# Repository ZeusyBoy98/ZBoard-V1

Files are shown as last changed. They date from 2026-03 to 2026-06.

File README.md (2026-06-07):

# ZBoard-V1
Video: https://github.com/ZeusyBoy98/ZBoard-V1/blob/main/IMG/ZBoard-V1-Video.mp4.  
The ultimate minimalistic 75% low-profile keyboard that fits my needs!
Made for Hack Club Fallout.

## Zine
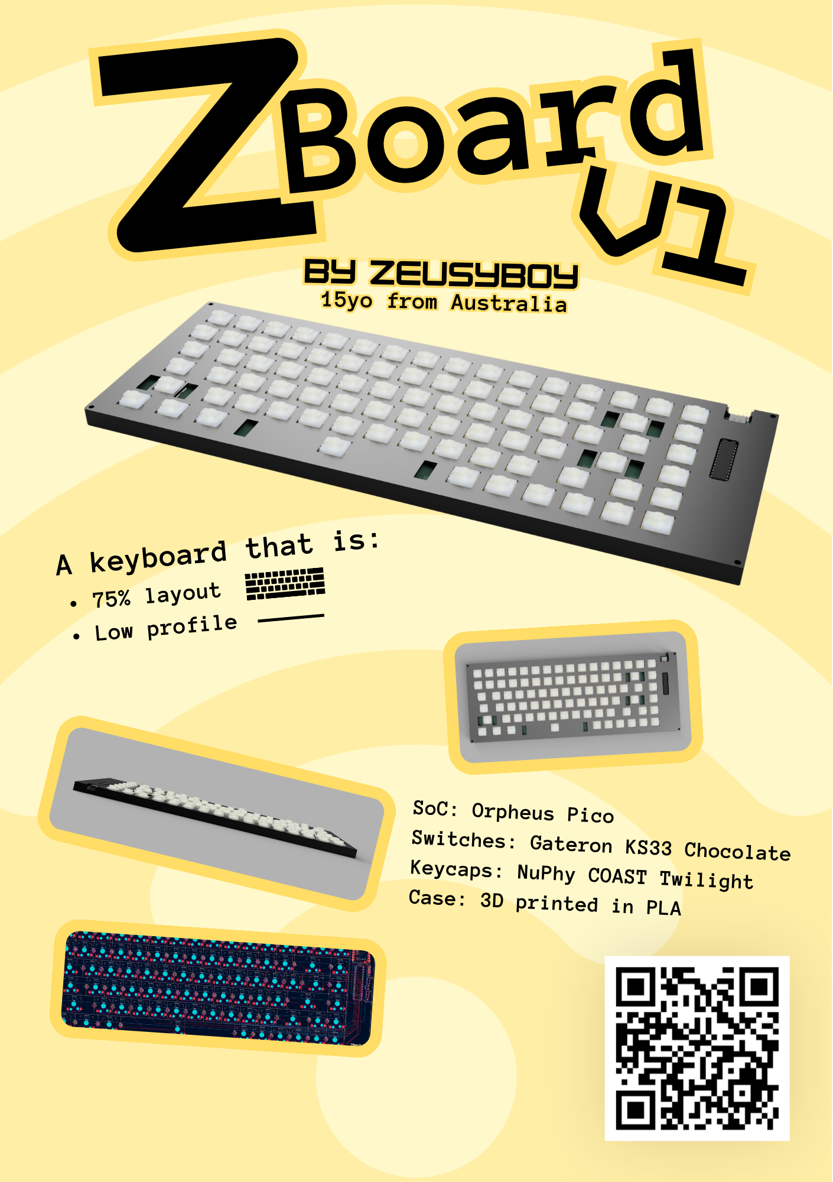
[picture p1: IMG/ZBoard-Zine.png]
zine


## What does it do?
It's a 75% low-profile keyboard with Gateron KS33 Chocolate Switches, NuPhy COAST Twilight Keycaps, and a 3D printed shell and plate.

## Why?
Because I hate my current keyboard options. I have a Corsair K70 Core which sucks for anything other than gaming, and some old HP keyboard which doesn't register switch presses half the time. So I decided to build my own keyboard. My requirements were for it to be low profile & 75%, so it can fit anywere for any situation, and use switches which I really enjoy pressing. In the end, this is the design I came up with and I could not be happier.

## Motivation
I don't have a good keyboard. My options are a gaming keyboard that double presses, or a membrane keyboard that doesn't press. This should fix both those issues and be actually enjoyable to use.

## How?
In order to make this project for yourself, you'll need to purchase/3D print the items in the bill of materials below.

| Qty | Component | Link | Price Individual (USD) | Price Sum (USD) |
| --- | --- | --- | --- | --- |
| 100 | Diode | [LCSC](https://www.lcsc.com/product-detail/C917030.html?s_z=n_1N4148W) | 0.0058 | 0.58 |
| 1 | Switches (110 KS33 Chocolate) | [Gateron](https://www.gateron.com/products/gateron-ks-33-low-profile-20-chocolate-switch?VariantsId=11140) | 39.60 | 39.60 |
| 1 | Hotswap Sockets | [Gateron](https://www.gateron.com/products/gateron-low-profile-switch-hot-swap-pcb-socket?VariantsId=10234)  | 11.00 | 11.00 |
| 1 | Stabilizers | [Gateron](https://www.gateron.com/products/gateron-low-profile-plate-mounted-stabilizer?VariantsId=10540) | 8.00 | 8.00 |
| 1 | Orpheus Pico | Hack Club Flavourtown | Already owned | Already owned |
| 1 | Heat set insert | [Core Electronics](https://core-electronics.com.au/brass-heat-set-inserts-for-plastic-m3-x-3mm-50-pack.html) | Already owned | (8.39) |
| 1 | 5mm M3 Screw | [Core Electronics](https://core-electronics.com.au/machine-screw-m3-5mm-length-phillips-25-pack.html) | Already owned | (2.24) |
| 1 | Case Pieces | CAD/ZBoard-V1-Print.3mf | 3D printing (220g filament) | |
| 1 | Keycap Set | CAD/ZBoard-V1-Print.3mf | 3D printing<br>(70g filament) | (Total 3D printing: 4.61) |
| 1 | PCB | PCB/production/ZBoard_V1.zip | | 21.90 |
| Shipping | | | | 8.60+21.28+10.77=40.65 |
| Total | | | | 99.83 |

### Build Guide:

#### 1. Preparation<br>
Before starting, make sure you have:
<ul>
<li>All components from the BOM
<li>A soldering iron + solder
<li>Tweezers (there are lots of small components)
<li>Flux (helpful)
<li>A screwdriver
<li>A 3D printer (or get the printed parts from someone else) - Print file at CAD/ZBoard-v1-Print.3mf
</ul>

#### 2. Soldering
Take your pcb and begin soldering components to it<br>
Recommended order:
<ul>
<li>SMD Components (Diodes, hot swap sockets)
<li>Microcontroller (Orpheus Pico)
</ul>

#### 3. Switches + Stabilizers
Insert each individual keyboard switch first, then do the stabilizers. Make sure every switch is properly seated in the socket.

#### 4. Case + Keycaps
<ul>
<li>3D print the case pieces and keycaps.
<li>Insert heat-set inserts with soldering iron into holes in bottom part of case.
<li>Place PCB into case and screw case closed with M3 Screws
<li>Put keycaps onto switches
</ul>

#### 5. Flash ZMK firmware
<ul>
<li>Plug the keyboard in via USB
<li>Double press the boot button to enter bootloader
<li>A new USB drive will appear
<li>Copy Firmware/zboard_zboardv1_default.uf2 onto the new USB drive
<li>Wait for Firmware to finish flashing
</ul>

Enjoy your ZBoard!

## Video
video

## Renders
Note: these renders are from the old version so they don't show the pi pico
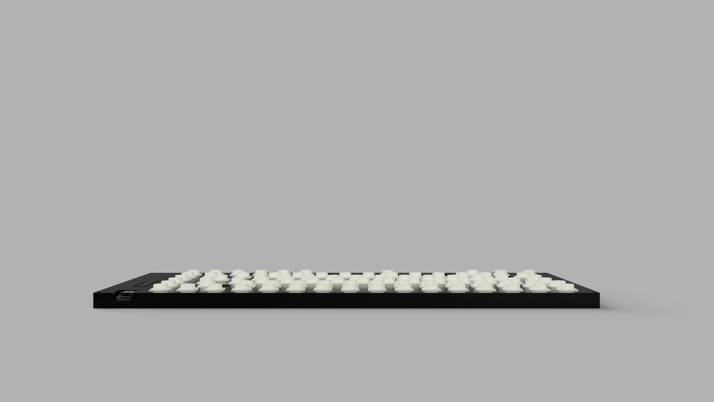
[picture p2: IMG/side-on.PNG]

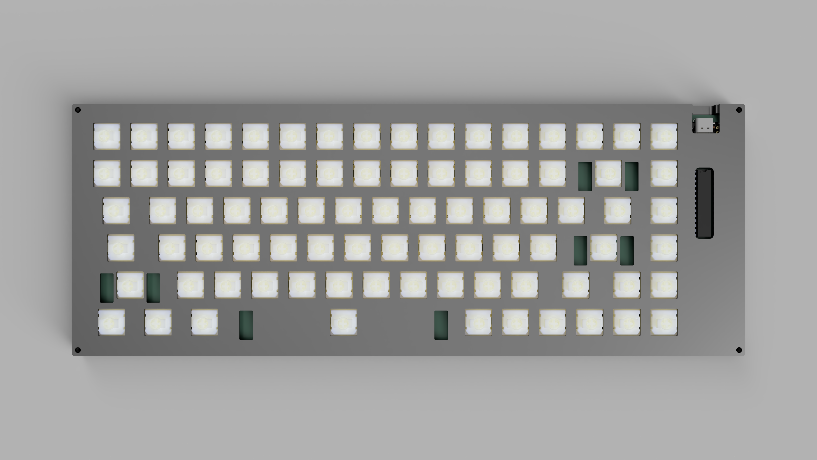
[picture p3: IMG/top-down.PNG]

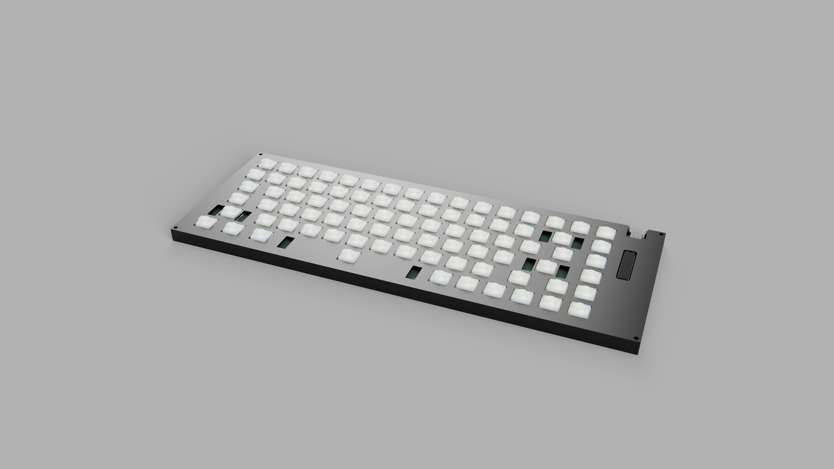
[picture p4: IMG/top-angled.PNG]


## Designing
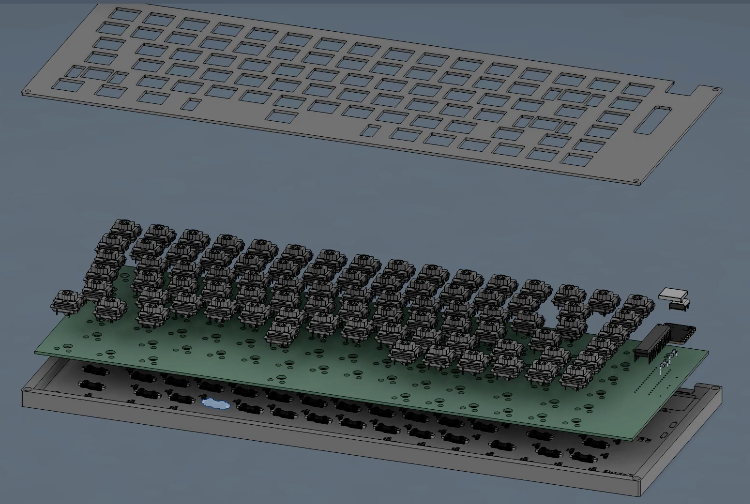
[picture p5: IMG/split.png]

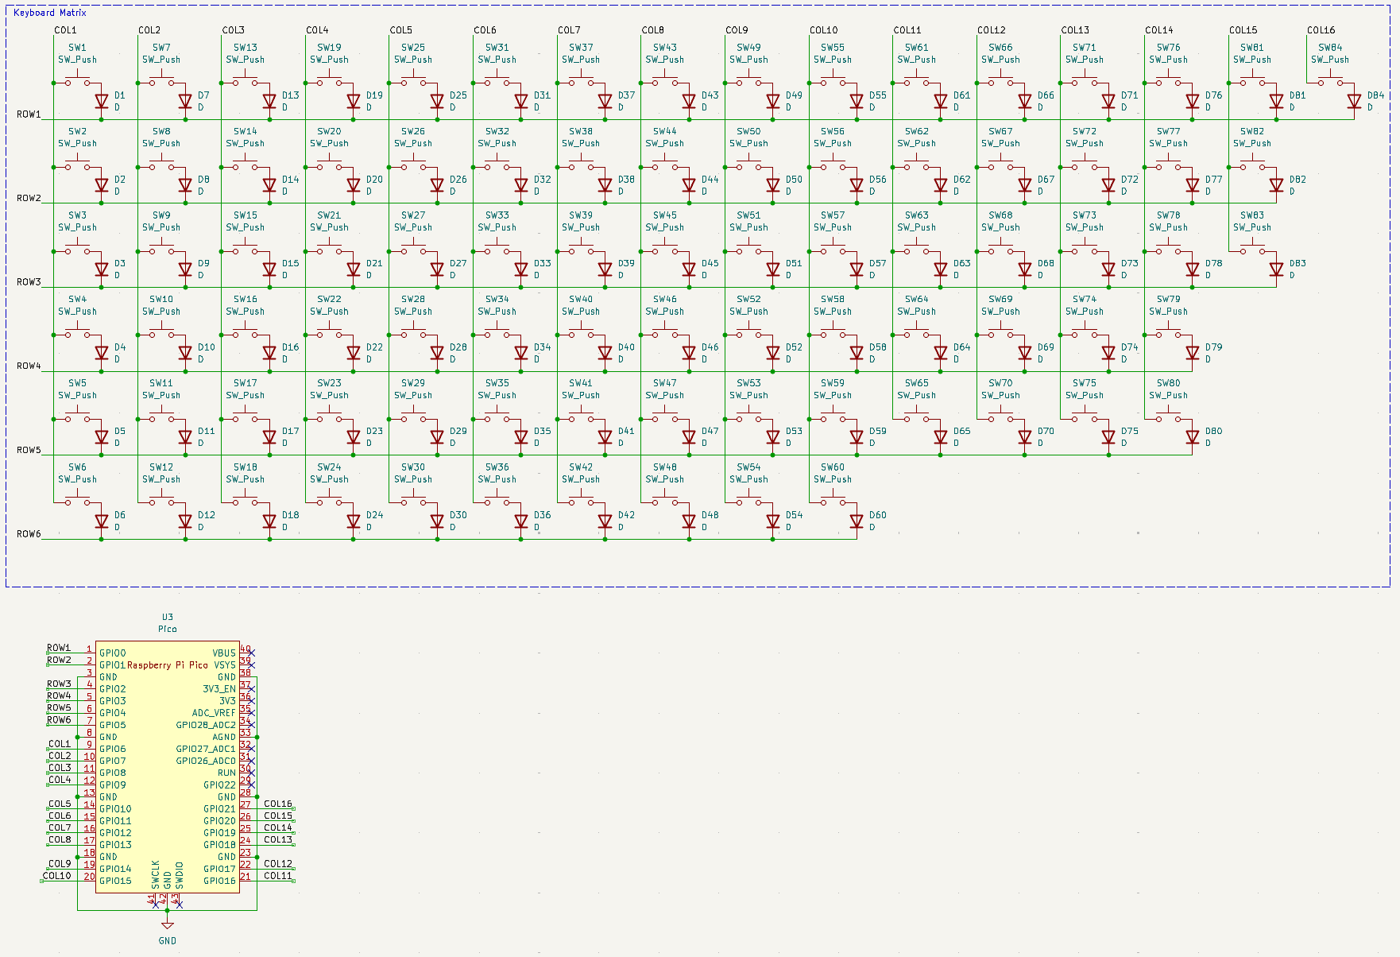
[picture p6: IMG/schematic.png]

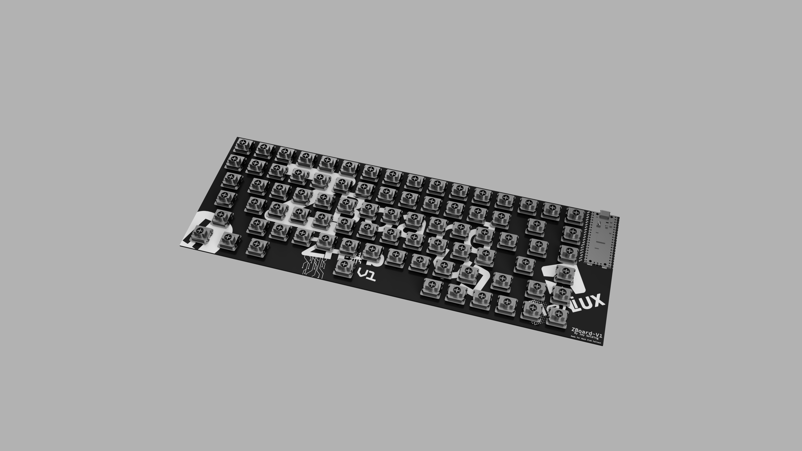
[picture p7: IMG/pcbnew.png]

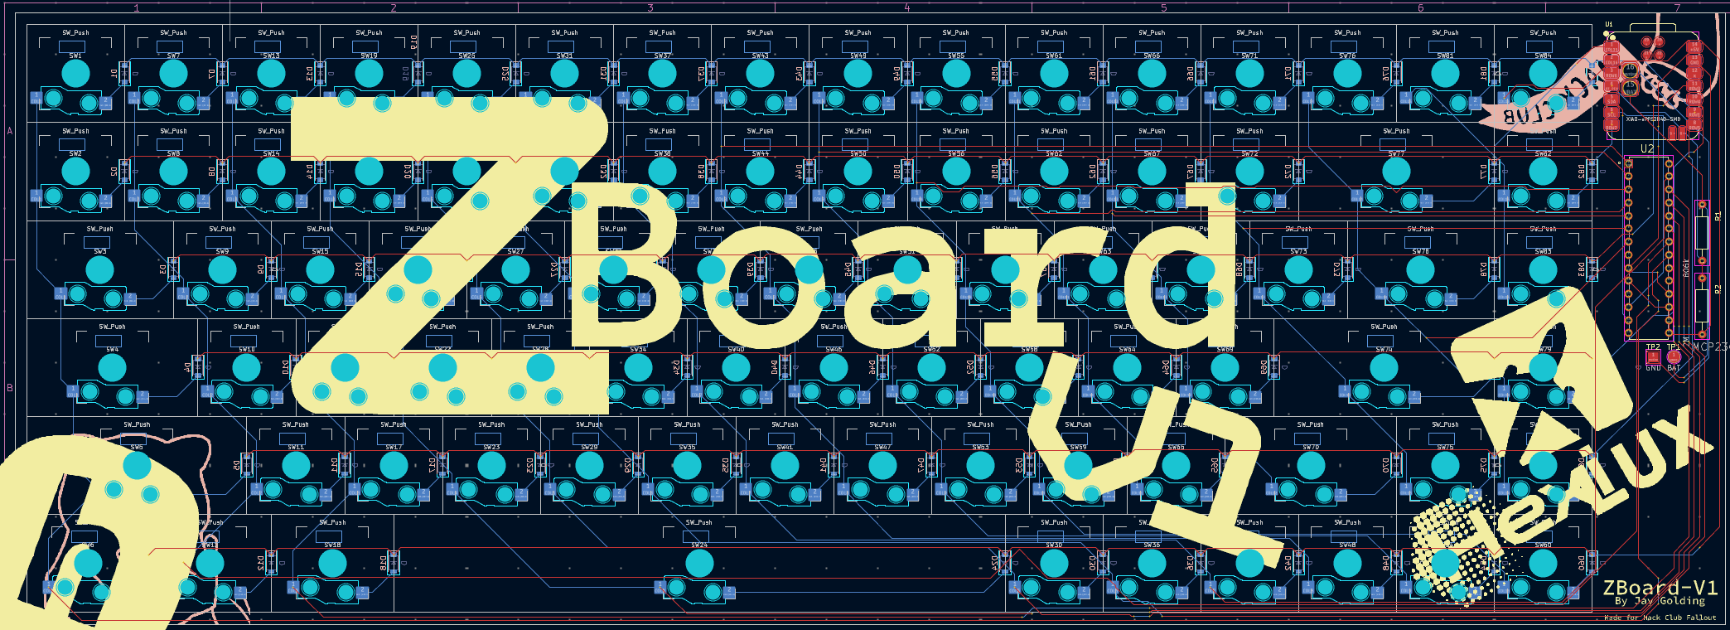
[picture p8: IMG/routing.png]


Here's the version with more personality:
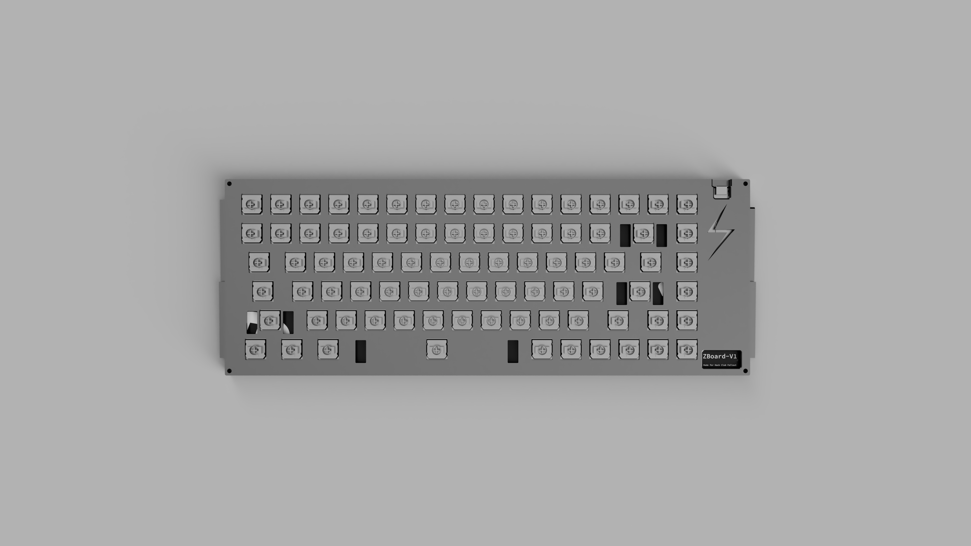
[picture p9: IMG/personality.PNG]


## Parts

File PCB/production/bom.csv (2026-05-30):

Designator | Footprint | Quantity | Value | LCSC Part #
D1, D10, D11, D12, D13, D14, D15, D16, D17, D18, D19, D2, D20, D21, D22, D23, D24, D25, D26, D27, D28, D29, D3, D30, D31, D32, D33, D34, D35, D36, D37, D38, D39, D4, D40, D41, D42, D43, D44, D45, D46, D47, D48, D49, D5, D50, D51, D52, D53, D54, D55, D56, D57, D58, D59, D6, D60, D61, D62, D63, D64, D65, D66, D67, D68, D69, D7, D70, D71, D72, D73, D74, D75, D76, D77, D78, D79, D8, D80, D81, D82, D83, D84, D9 | D_SOD-123 | 84 | D
SW1, SW10, SW11, SW13, SW14, SW15, SW16, SW17, SW19, SW2, SW20, SW21, SW22, SW23, SW25, SW26, SW27, SW28, SW29, SW30, SW31, SW32, SW33, SW34, SW35, SW36, SW37, SW38, SW39, SW40, SW41, SW42, SW43, SW44, SW45, SW46, SW47, SW48, SW49, SW50, SW51, SW52, SW53, SW54, SW55, SW56, SW57, SW58, SW59, SW60, SW61, SW62, SW63, SW64, SW65, SW66, SW67, SW68, SW69, SW7, SW71, SW72, SW73, SW75, SW76, SW79, SW8, SW80, SW81, SW82, SW83, SW84, SW9 | Gateron-KS33-Hotswap-1U | 73 | SW_Push
SW12, SW18, SW6 | Gateron-KS33-Hotswap-1.25U | 3 | SW_Push
SW24 | Gateron-KS33-Hotswap-6.25U | 1 | SW_Push
SW3, SW78 | Gateron-KS33-Hotswap-1.5U | 2 | SW_Push
SW4, SW70 | Gateron-KS33-Hotswap-1.75U | 2 | SW_Push
SW5, SW74 | Gateron-KS33-Hotswap-2.25U | 2 | SW_Push
SW77 | Gateron-KS33-Hotswap-2U | 1 | SW_Push
U3 | RPi_Pico_SMD_TH | 1 | Pico

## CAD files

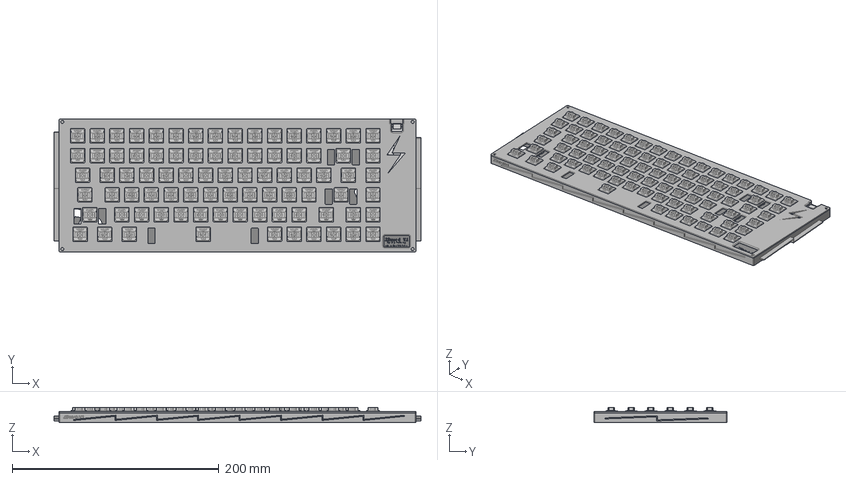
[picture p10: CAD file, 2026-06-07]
CAD/Personality/ZBoard-V1-Full.stp
355.0 x 129.0 x 14.6 mm

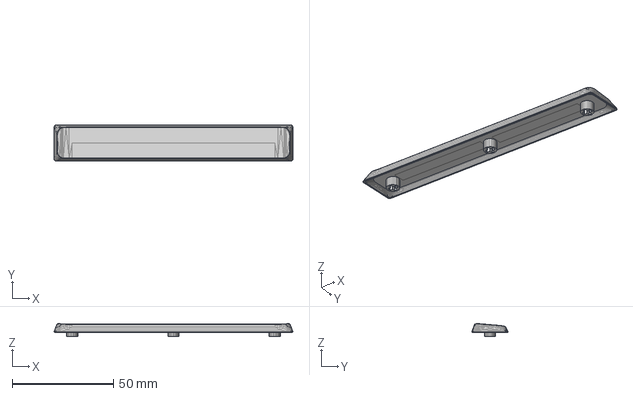
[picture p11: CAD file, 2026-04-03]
CAD/Keycaps/Keycap-6.25u.step
118.0 x 18.0 x 6.23 mm

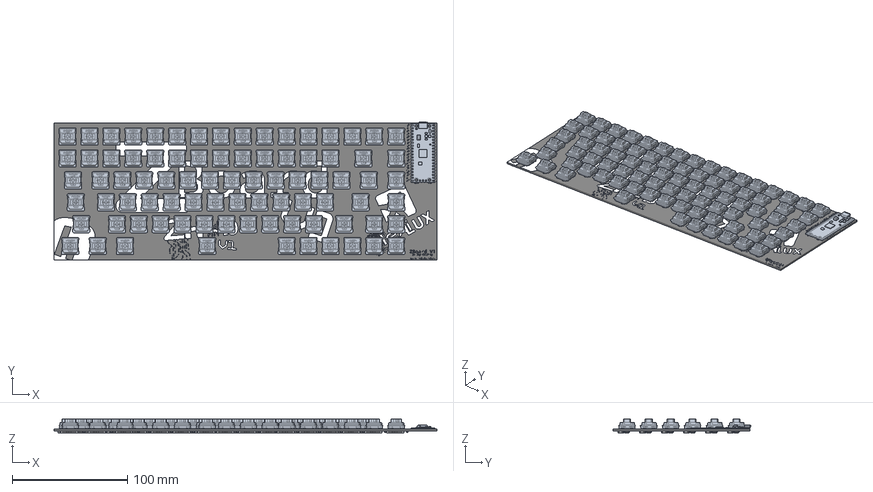
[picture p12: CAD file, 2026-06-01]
CAD/Parts/ZBoard-V1-PCB.step
333.0 x 119.7 x 12.5 mm
ZBoard-V1-PCB 1.1.1
D_SOD-123 x 84
Gateron-KS33-Socket x 84
KS-33 x 84
ZBoard V1_silkscreen x 2
ZBoard V1_PCB

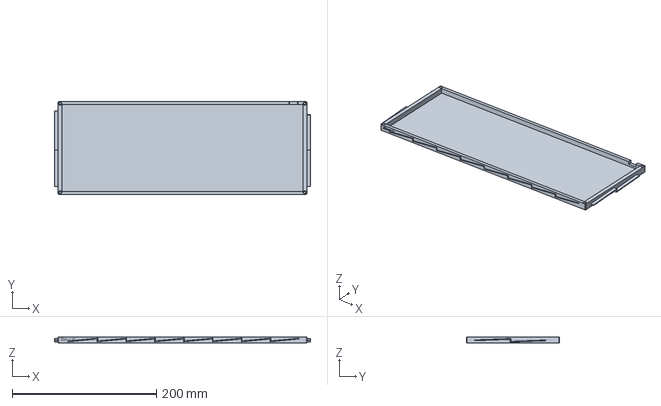
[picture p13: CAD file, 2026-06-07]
CAD/Personality/ZBoard-V1-Bottom.stp
355.0 x 129.0 x 9.00 mm

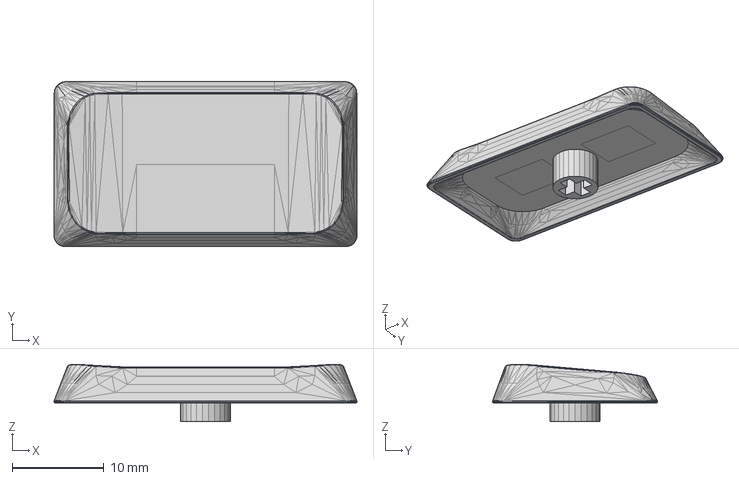
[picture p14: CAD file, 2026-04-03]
CAD/Keycaps/Keycap-1.5u.step
33.0 x 18.0 x 6.23 mm

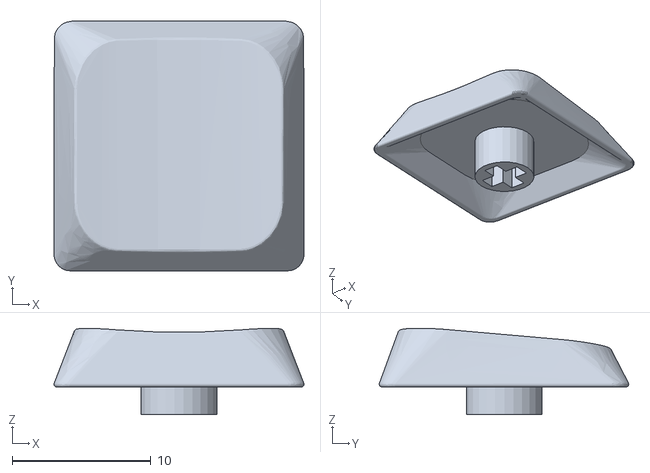
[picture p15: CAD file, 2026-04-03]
CAD/Parts/keycap.stl
18.0 x 18.0 x 6.23

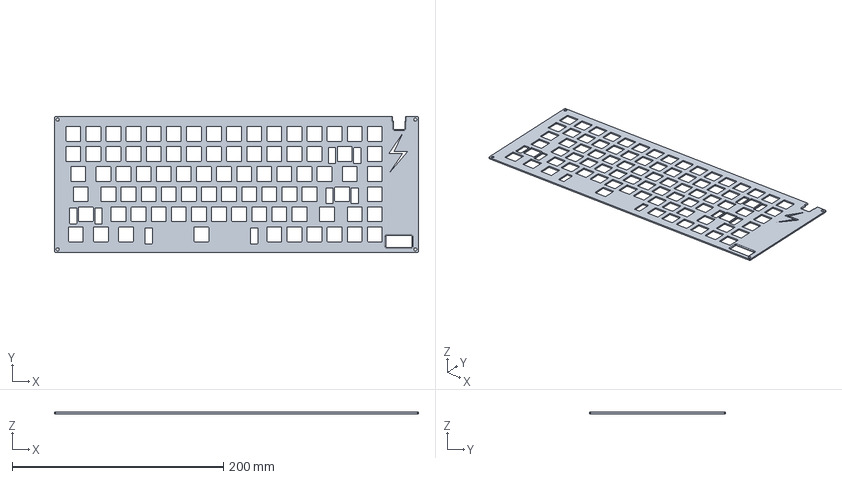
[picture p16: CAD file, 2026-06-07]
CAD/Personality/ZBoard-V1-Top.stp
345.0 x 129.0 x 1.50 mm

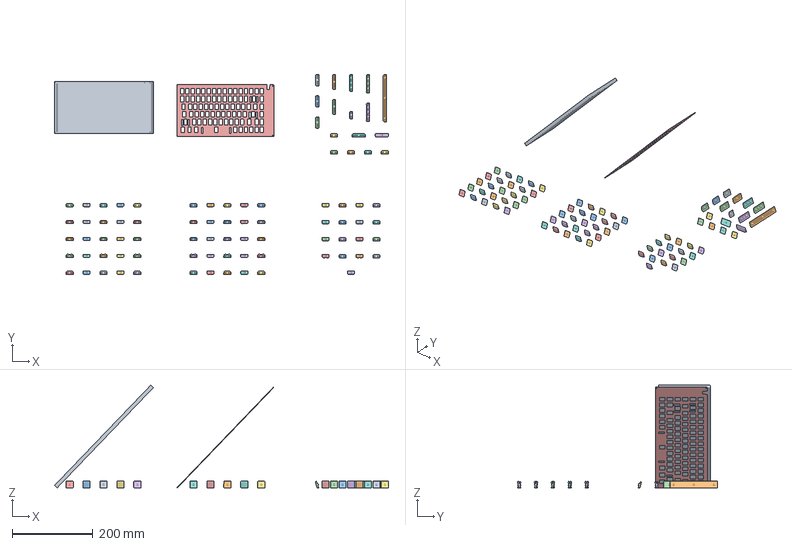
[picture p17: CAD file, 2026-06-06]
CAD/ZBoard-V1-Print.3mf
828.3 x 496.2 x 255.1 mm
Keycap-6.25u.step
Keycap-1u.stl x 73
Keycap-2.25u.step x 2
Keycap-2u.step
Keycap-1.75u.step x 2
Keycap-1.5u.step x 2
Keycap-1.25u.step x 3
Plate

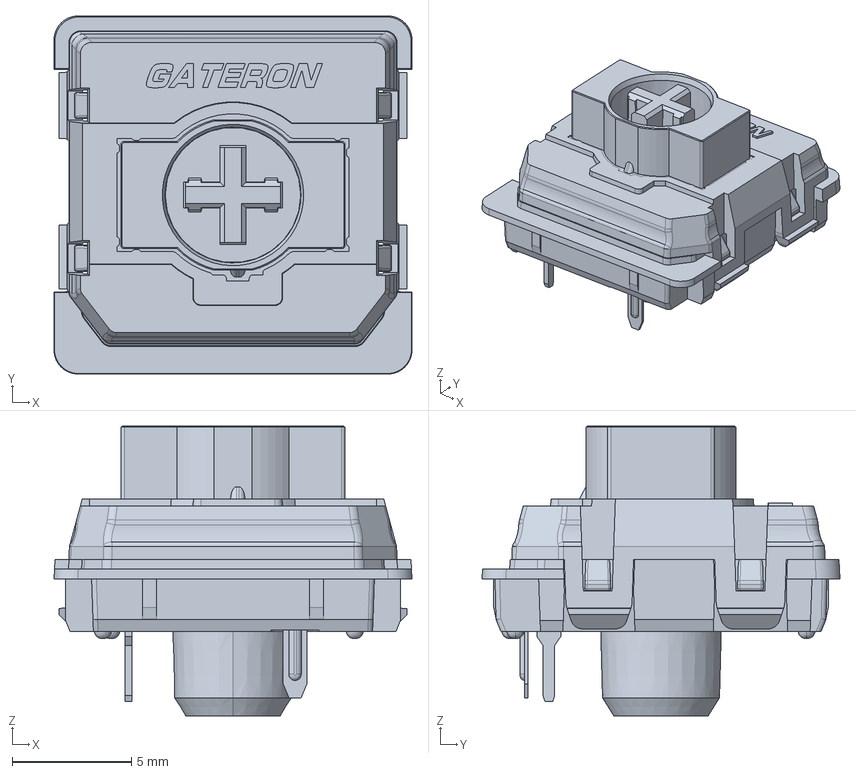
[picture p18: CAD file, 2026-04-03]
CAD/Parts/KS-33 Low Profile 2.0.stp
15.0 x 15.0 x 12.1 mm

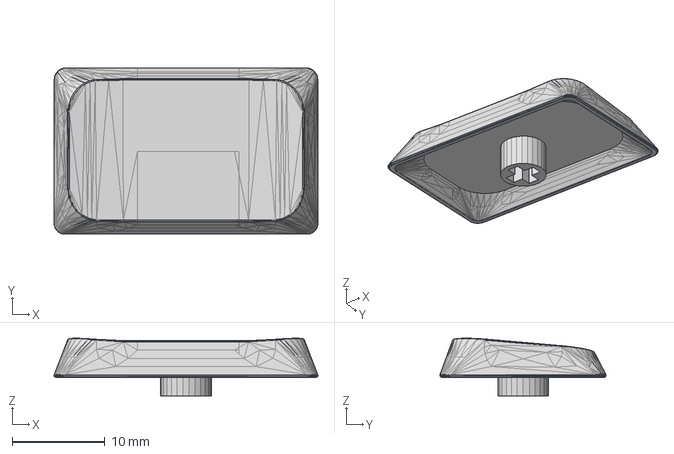
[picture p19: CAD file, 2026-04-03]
CAD/Keycaps/Keycap-1.25u.step
28.5 x 18.0 x 6.23 mm

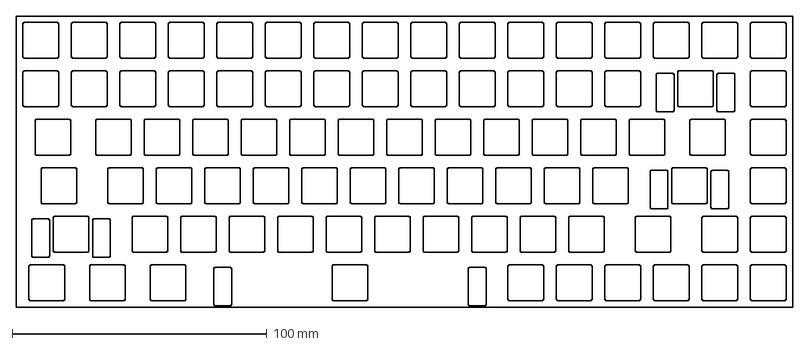
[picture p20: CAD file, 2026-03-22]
CAD/Parts/plate.dxf
304.8 x 114.3 mm

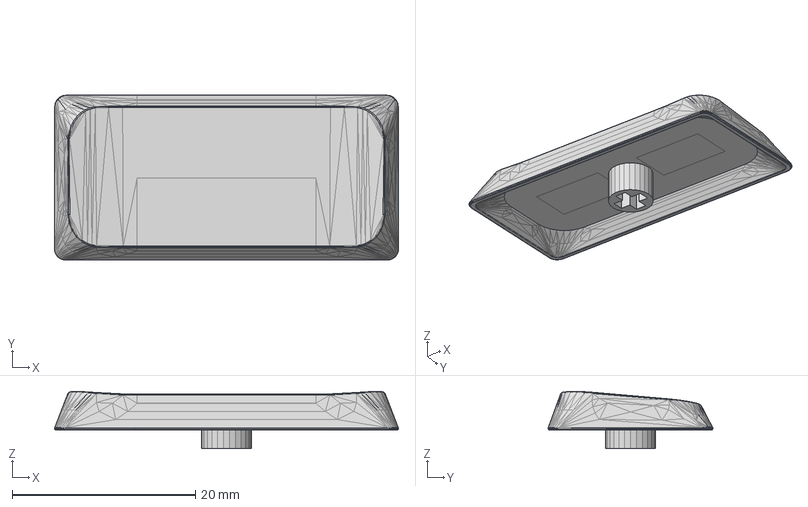
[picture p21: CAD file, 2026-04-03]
CAD/Keycaps/Keycap-1.75u.step
37.5 x 18.0 x 6.23 mm

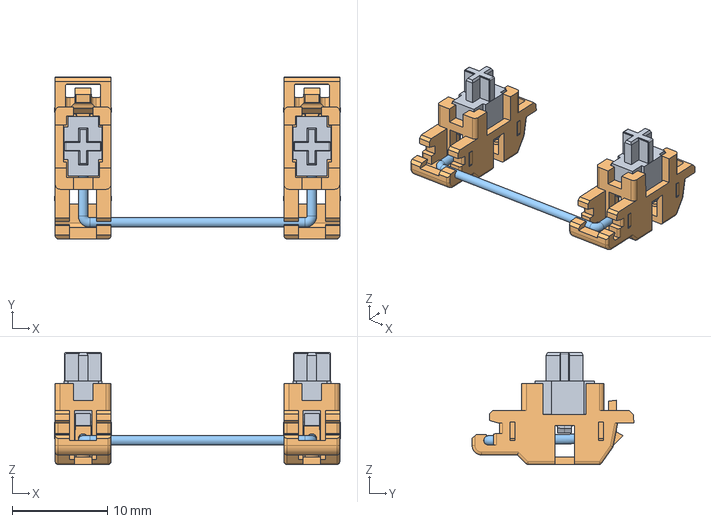
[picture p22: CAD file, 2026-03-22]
CAD/Parts/low profile stabilizer.stp
30.0 x 17.0 x 11.8 mm

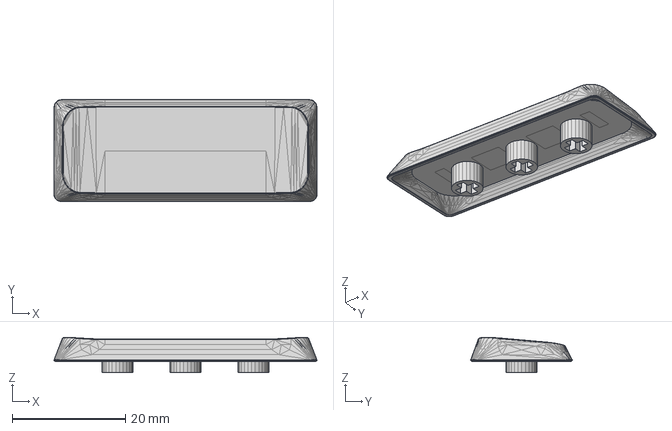
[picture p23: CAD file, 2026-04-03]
CAD/Keycaps/Keycap-2.25u.step
46.5 x 18.0 x 6.23 mm

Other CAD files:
CAD/Keycaps/Keycap-2u.step
CAD/ZBoard-V1-Full.stp
CAD/ZBoard-V1-Top.stp
CAD/Personality/ZBoard-V1-Full.f3d
CAD/ZBoard-V1-Bottom.stp
CAD/ZBoard-V1-Full.f3d

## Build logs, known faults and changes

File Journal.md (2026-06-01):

# ZBoard-V1 — Journal Export

- Exported at: 2026-06-01T06:50:49Z
- Project ID: 361
- Entries: 19

## Entry 1
- ID: 127
- Author: ZeusyBoy
- Created At: 2026-03-17T12:45:55Z

### Content

I began the initial schematic and research for my custom keyboard, ZBoard. I had to find the right resistors, but other than that, it was pretty simple due to the blueprint keyboard guide. 
Screenshot 2026-03-17 at 8.45.19 pm.png
Next step will be footprint, then BOM, then case designing.

### Recording Links

- https://public.lapse-hackclub.link/timelapses/Uo5dGTP_hJ6y/timelapse-Uo5dGTP_hJ6y.mp4

## Entry 2
- ID: 150
- Author: ZeusyBoy
- Created At: 2026-03-18T02:41:26Z

### Content

I've done some research and I decided I want to do a top-mount keyboard.
Top Mount Keyboard

I might try and model and 3d print the switch plate, or I might buy a metal one. I have also made the decision to not integrate a usb hub into this keyboard design. I would like to keep it minimal.

I will also be using low profile switches and I want it to be hot swap.

Next step will be routing the PCB.

### Recording Links

- https://public.lapse-hackclub.link/timelapses/3ClfFH3FVTJO/timelapse-3ClfFH3FVTJO.mp4

## Entry 3
- ID: 194
- Author: ZeusyBoy
- Created At: 2026-03-19T02:25:45Z

### Content

Switched to 75% keyboard for need of arrow keys and delete. Began routing pcb, took ages and only around halfway.
New layout:
Screenshot 2026-03-19 102514.png

## Entry 4
- ID: 227
- Author: ZeusyBoy
- Created At: 2026-03-19T23:05:32Z

### Content

I finished routing the pcb. The process was slow and painful due to the many overlapping row and column lines that I had to route, but I managed to do it on only the front and back. This will minimize cost when I get the pcb made. Here's a photo of the finalized routing:
Screenshot 2026-03-20 at 7.02.12 am.png

The next step will be to make the outline of the pcb and then I think I'll do some silkscreen work to customize it and make it look really cool. Following that, it'll be time to make a BOM, order the pcb, and start working on the case and plate.

All in all, I'm very excited about where this project is heading, and I hope it goes well in the end!

### Recording Links

- https://public.lapse-hackclub.link/timelapses/f3ftuR1VCmZb/timelapse-f3ftuR1VCmZb.mp4

## Entry 5
- ID: 272
- Author: ZeusyBoy
- Created At: 2026-03-21T08:00:48Z

### Content

I added some simple silkscreen and an edge so now I can start making a more complicated silkscreen yay!

Screenshot 2026-03-21 at 4.00.21 pm.png

### Recording Links

- https://public.lapse-hackclub.link/timelapses/XlE8kGLjVOpP/timelapse-XlE8kGLjVOpP.mp4

## Entry 6
- ID: 280
- Author: ZeusyBoy
- Created At: 2026-03-21T14:27:45Z

### Content

I realized that my hot swap sockets were on the wrong side, so I had to switch them. Then I fully rerouted the PCB and also added the 3d models so I could preview it. It's cool!
Screenshot 2026-03-21 at 10.26.56 pm.png

The next step will be the BOM and case.

### Recording Links

- https://public.lapse-hackclub.link/timelapses/l-vrTU19BW00/timelapse-l-vrTU19BW00.mp4

## Entry 7
- ID: 306
- Author: ZeusyBoy
- Created At: 2026-03-22T04:38:08Z

### Content

So this is beginning to get waaaaay more painful. When I finished routing, I thought I got the hard bit out of the way, but nope. The case is just research and pain. Multiplied by the fact that I'm using low profile switches, which means there's less existing documentation for me to draw from. It's painful, but I'm working on it. Here's the case so far (it's very incomplete)
Screenshot 2026-03-22 at 12.36.46 pm.png

The next step will be to continue designing the case, and eventually writing firmware and then shipping and ordering everything.

### Recording Links

- https://public.lapse-hackclub.link/timelapses/Eee9_k6OWJx0/timelapse-Eee9_k6OWJx0.mp4

## Entry 8
- ID: 318
- Author: ZeusyBoy
- Created At: 2026-03-22T13:26:04Z

### Content

Finalized the case, although I will need to add a tilt mechanism probably, but other than that, I think it's pretty good. I chose to use heat-set inserts and screws to attach the plate to the body, as this is the easiest and most secure way for me to achieve it.
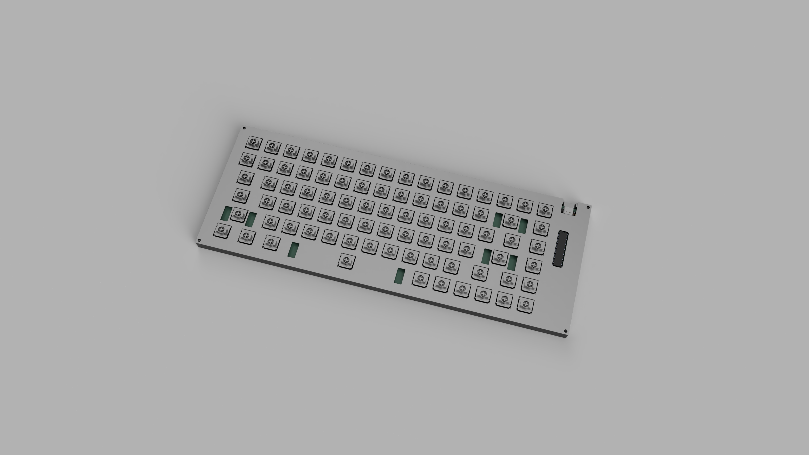
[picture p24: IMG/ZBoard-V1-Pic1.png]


Next I'll add a tilting mechanism to the case and then start working on the renders and firmware!

### Recording Links

- https://public.lapse-hackclub.link/timelapses/gOxBCL1u9J_1/timelapse-gOxBCL1u9J_1.mp4

## Entry 9
- ID: 365
- Author: ZeusyBoy
- Created At: 2026-03-23T13:10:35Z

### Content

I simply added a kickstand to the keyboard because I like having functioning wrists, and I began animating a cool product trailer. I decided I wanted a trailer because it looks so freaking cool, and I'll be more proud of the project because of it. 
Screenshot 2026-03-23 at 9.09.16 pm.png

Next steps are more animating of the trailer, and then firmware.

### Recording Links

- https://public.lapse-hackclub.link/timelapses/byWuJbqjkFzZ/timelapse-byWuJbqjkFzZ.mp4
- https://public.lapse-hackclub.link/timelapses/zVEwYgGqLT_5/timelapse-zVEwYgGqLT_5.mp4

## Entry 10
- ID: 480
- Author: ZeusyBoy
- Created At: 2026-03-26T09:26:46Z

### Content

I updated the BOM with shipping and the PCB, finished the renders and the video. Now my renders look all fancy and I love it!!! Then I fixed my readme so it actually says the stuff it needs to. Then I made my a journal.md in the repo itself.
Here are my fancy renders:




Next I have to work on polish. I'll go back and add some fancy silkscreen to my PCB, then make the case look a lot nicer. Once that's done, I can start working on the firmware, Zine, and finishing off the project.

### Recording Links

- https://lookout.hackclub.com/api/media/9ad27906-9c1c-402b-82a7-ba3f5e0180de/video.mp4

## Entry 11
- ID: 553
- Author: ZeusyBoy
- Created At: 2026-03-28T02:34:07Z

### Content

Started working on the firmware. I decided to use Vial because it's more customizable and better in the long run.
Screenshot 2026-03-28 at 10.33.35 am.png

### Recording Links

- https://lookout.hackclub.com/api/media/e5807c2d-5daf-4956-9c36-1b43065ea246/video.mp4

## Entry 12
- ID: 572
- Author: ZeusyBoy
- Created At: 2026-03-28T09:02:02Z

### Content

In these long 5 hours, I did the firmware. In one go. I don't know why I did it, it was a stupid idea. But I did it anyway. I started by trying to use QMK and vial because it is very configurable and C is nice. That turned out to be a terrible mistake due to my use of the MCP23017 I/O expander in my design. There is also the fact that QMK is not at all developed for wireless, so that ship sailed after the first 2 hours. So I boldly ventured into the ZMK. I had to learn whole new languages and do a lot of research. Eventually I managed to configure the batteries, bluetooth, and just normal keyboard function into a firmware that _might_ work. Fingers crossed I guess. Anyway, that's enough of that rant, here's a picture of some code:
Screenshot 2026-03-28 at 5.00.56 pm.png

At least the hardest part is now over. Time for some fun making my silkscreen nice and doing my Zine.

### Recording Links

- https://lookout.hackclub.com/api/media/042987c4-4ac2-45d1-9164-a88633e744a9/video.mp4
- https://lookout.hackclub.com/api/media/17672e43-8f5f-4fee-903b-d8c63b6ac66b/video.mp4

## Entry 13
- ID: 787
- Author: ZeusyBoy
- Created At: 2026-03-31T12:26:23Z

### Content

I finished up the silkscreen for the PCB, and it's looking very nice! I added some logo text, some of my previous projects, and some hack club branding, all making it come together to look like a very finished PCB.
Here's some nice images of the silkscreen:
Screenshot 2026-03-31 at 8.23.47 pm.png

Screenshot 2026-03-31 at 8.24.09 pm.png

Next I'll need to work on my Zine and do some more polishing up in order to reach the number of hours I need to get my grant.

### Recording Links

- https://lookout.hackclub.com/api/media/59ea0e75-f07b-4c41-972d-a5bb2ff4b0fc/video.mp4

## Entry 14
- ID: 940
- Author: ZeusyBoy
- Created At: 2026-04-02T13:15:09Z

### Content

I worked on and finished my Zine, and added some required files for submission. I'm considering 3D printing my keycaps because I don't have enough hours for my current BOM, but we'll see what happens.
Here's my Zine:
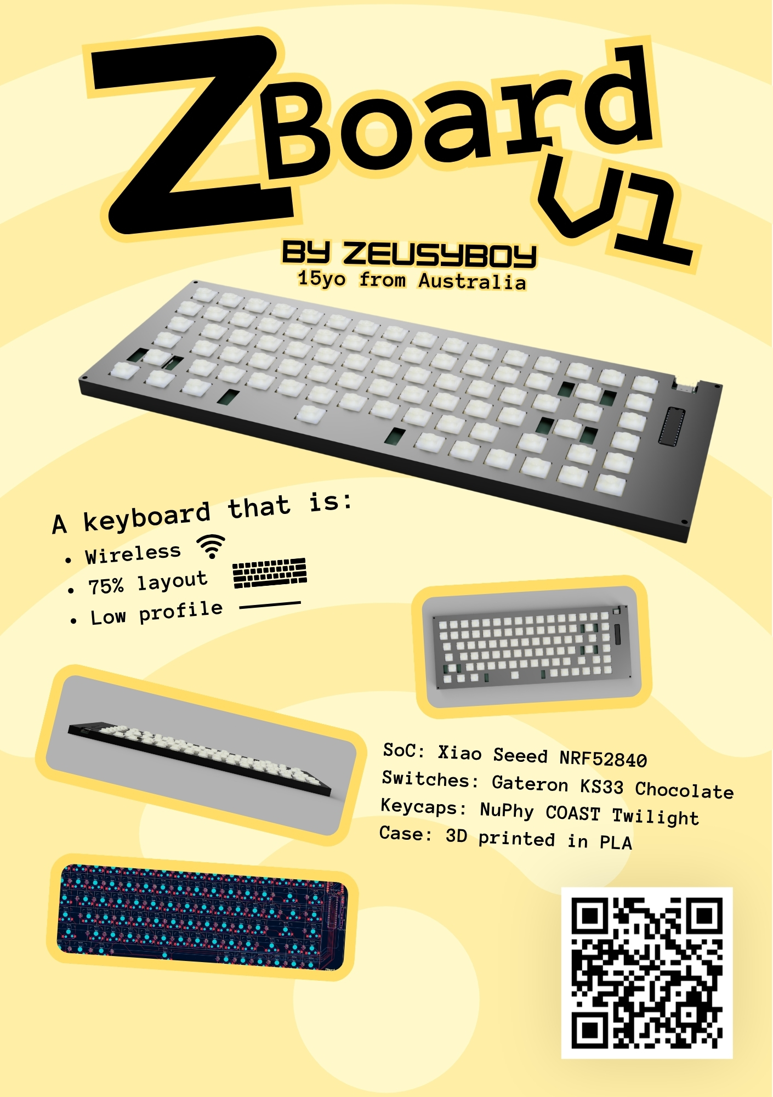
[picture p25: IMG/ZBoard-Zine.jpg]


### Recording Links

- https://lookout.hackclub.com/api/media/bb1f83d1-a4d0-499c-92a6-ba6d01571693/video.mp4

## Entry 15
- ID: 1009
- Author: ZeusyBoy
- Created At: 2026-04-03T09:36:22Z

### Content

Due to funding issues, I decided to switch to 3D printed keycaps, which only use 70g of filament. I used an existing model and then made the 1.25u, 1.5u, 1.75u, 2u, 2.25u, and 6.25u versions, so now I've saved extra money. I also switched from DigiKey to LCSC because shipping is way cheaper and so are the parts, so this might be the last journal, it's been a great experience and I can't wait to continue fallout and eventually reach 60 hours!

Here's the sliced 3D prints:
Screenshot 2026-04-03 at 5.35.48 pm.png

### Recording Links

- https://lookout.hackclub.com/api/media/ebc87cb0-e9c4-4029-9347-15c391199b8b/video.mp4
- https://lookout.hackclub.com/api/media/397b0e76-6181-4c3e-8b3c-059af7d92b72/video.mp4

## Entry 16
- ID: 1100
- Author: ZeusyBoy
- Created At: 2026-04-04T04:05:59Z

### Content

Firmware. I despise it. With the carry that is Large Language Models, I was able to get my firmware to build. So painful. I never want to experience that again. But this is it. All parts of the design are complete. I can now rest easy knowing I just have to build it. And I enjoy soldering, so it should be a treat.
Here's the file that caused me hours of pain just to get:
Screenshot 2026-04-04 at 11.58.50 am.png

### Recording Links

- https://lookout.hackclub.com/api/media/154e51e0-9e6d-4059-a7aa-2a8062b621ff/video.mp4
- https://lookout.hackclub.com/api/media/fbcdca53-77b4-44ed-bbea-8e031e9ad72e/video.mp4

## Entry 17
- ID: 1108
- Author: ZeusyBoy
- Created At: 2026-04-04T06:33:18Z

### Content

I fixed the issues the pre-ship scan picked up on, so now this should be the last journal. I'm very proud of how far this project has come and I'm excited for what I'll build in the future.
Screenshot 2026-04-04 at 2.32.28 pm.png

### Recording Links

- https://lookout.hackclub.com/api/media/a9feb8dd-c82a-4c6e-a22d-52dd6ef54fc8/video.mp4
- https://lookout.hackclub.com/api/media/131b288a-2752-48f8-8de8-bcf612abe516/video.mp4

## Entry 18
- ID: 10404
- Author: ZeusyBoy
- Created At: 2026-05-30T13:55:52Z

### Content

I changed the schematic to the Orpheus Pico, rerouted the board with it, and then redesigned the case around it. The only remaining steps are to rewrite the firmware (in qmk this time) and change the Zine a little. Funsies!!!
Screenshot 2026-05-30 at 9.55.13 pm.png

### Recording Links

- https://lookout.hackclub.com/api/media/176e17e2-8b7a-4e85-95cf-7dbb9e5265c5/video.mp4

## Entry 19
- ID: 10634
- Author: ZeusyBoy
- Created At: 2026-05-31T11:10:30Z

### Content

Tried to keep going in QMK, that failed because AAAAHHHH so switched to ZMK, then remembered how PAINFUL BUILDING ZMK FIRMWARE IS. Gonna try github actions method tomorrow but for now I need a break.
Screenshot 2026-05-31 at 7.10.11 pm.png

### Recording Links

- https://lookout.hackclub.com/api/media/3b318009-dafd-40ed-8468-192e210fb2cd/video.mp4

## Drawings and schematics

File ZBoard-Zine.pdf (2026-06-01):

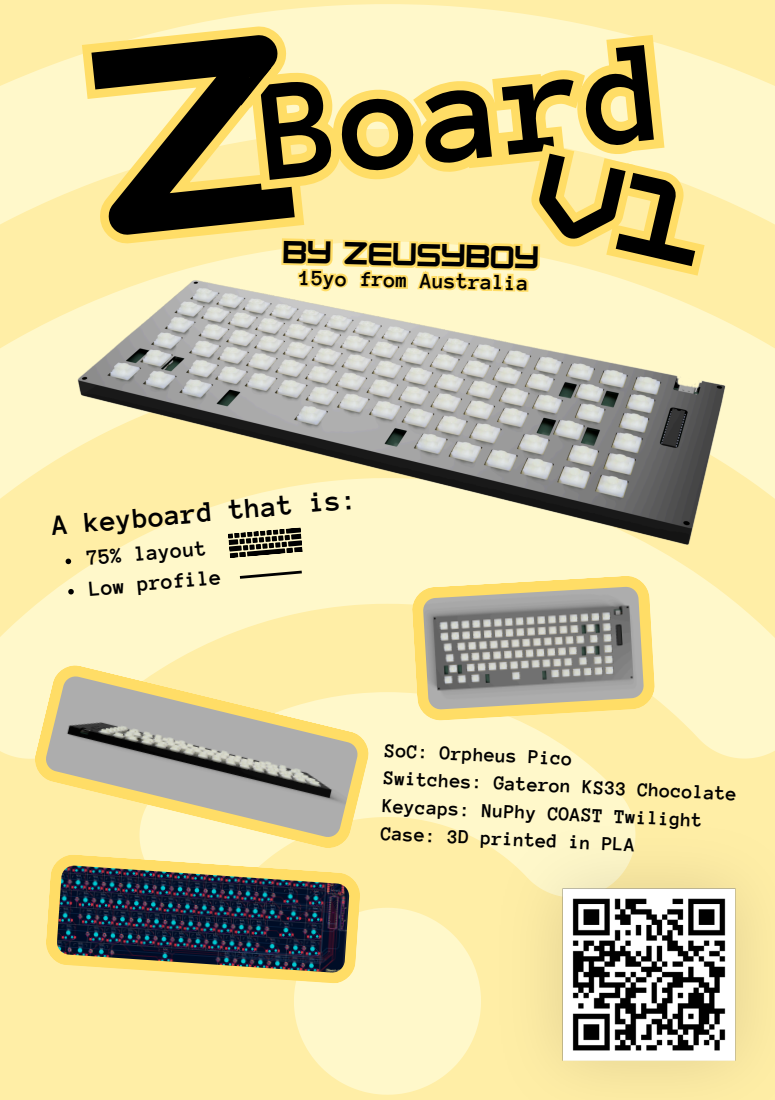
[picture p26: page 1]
ZBoard BoardV1; 75% layout Low profile; BByy ZZeeuussyyBBooyy

15yo from Australia 115yo from Australia 5yo from Australia

A keyboard that is:

SoC: Orpheus Pico

Switches: Gateron KS33 Chocolate

Keycaps: NuPhy COAST Twilight

Case: 3D printed in PLA

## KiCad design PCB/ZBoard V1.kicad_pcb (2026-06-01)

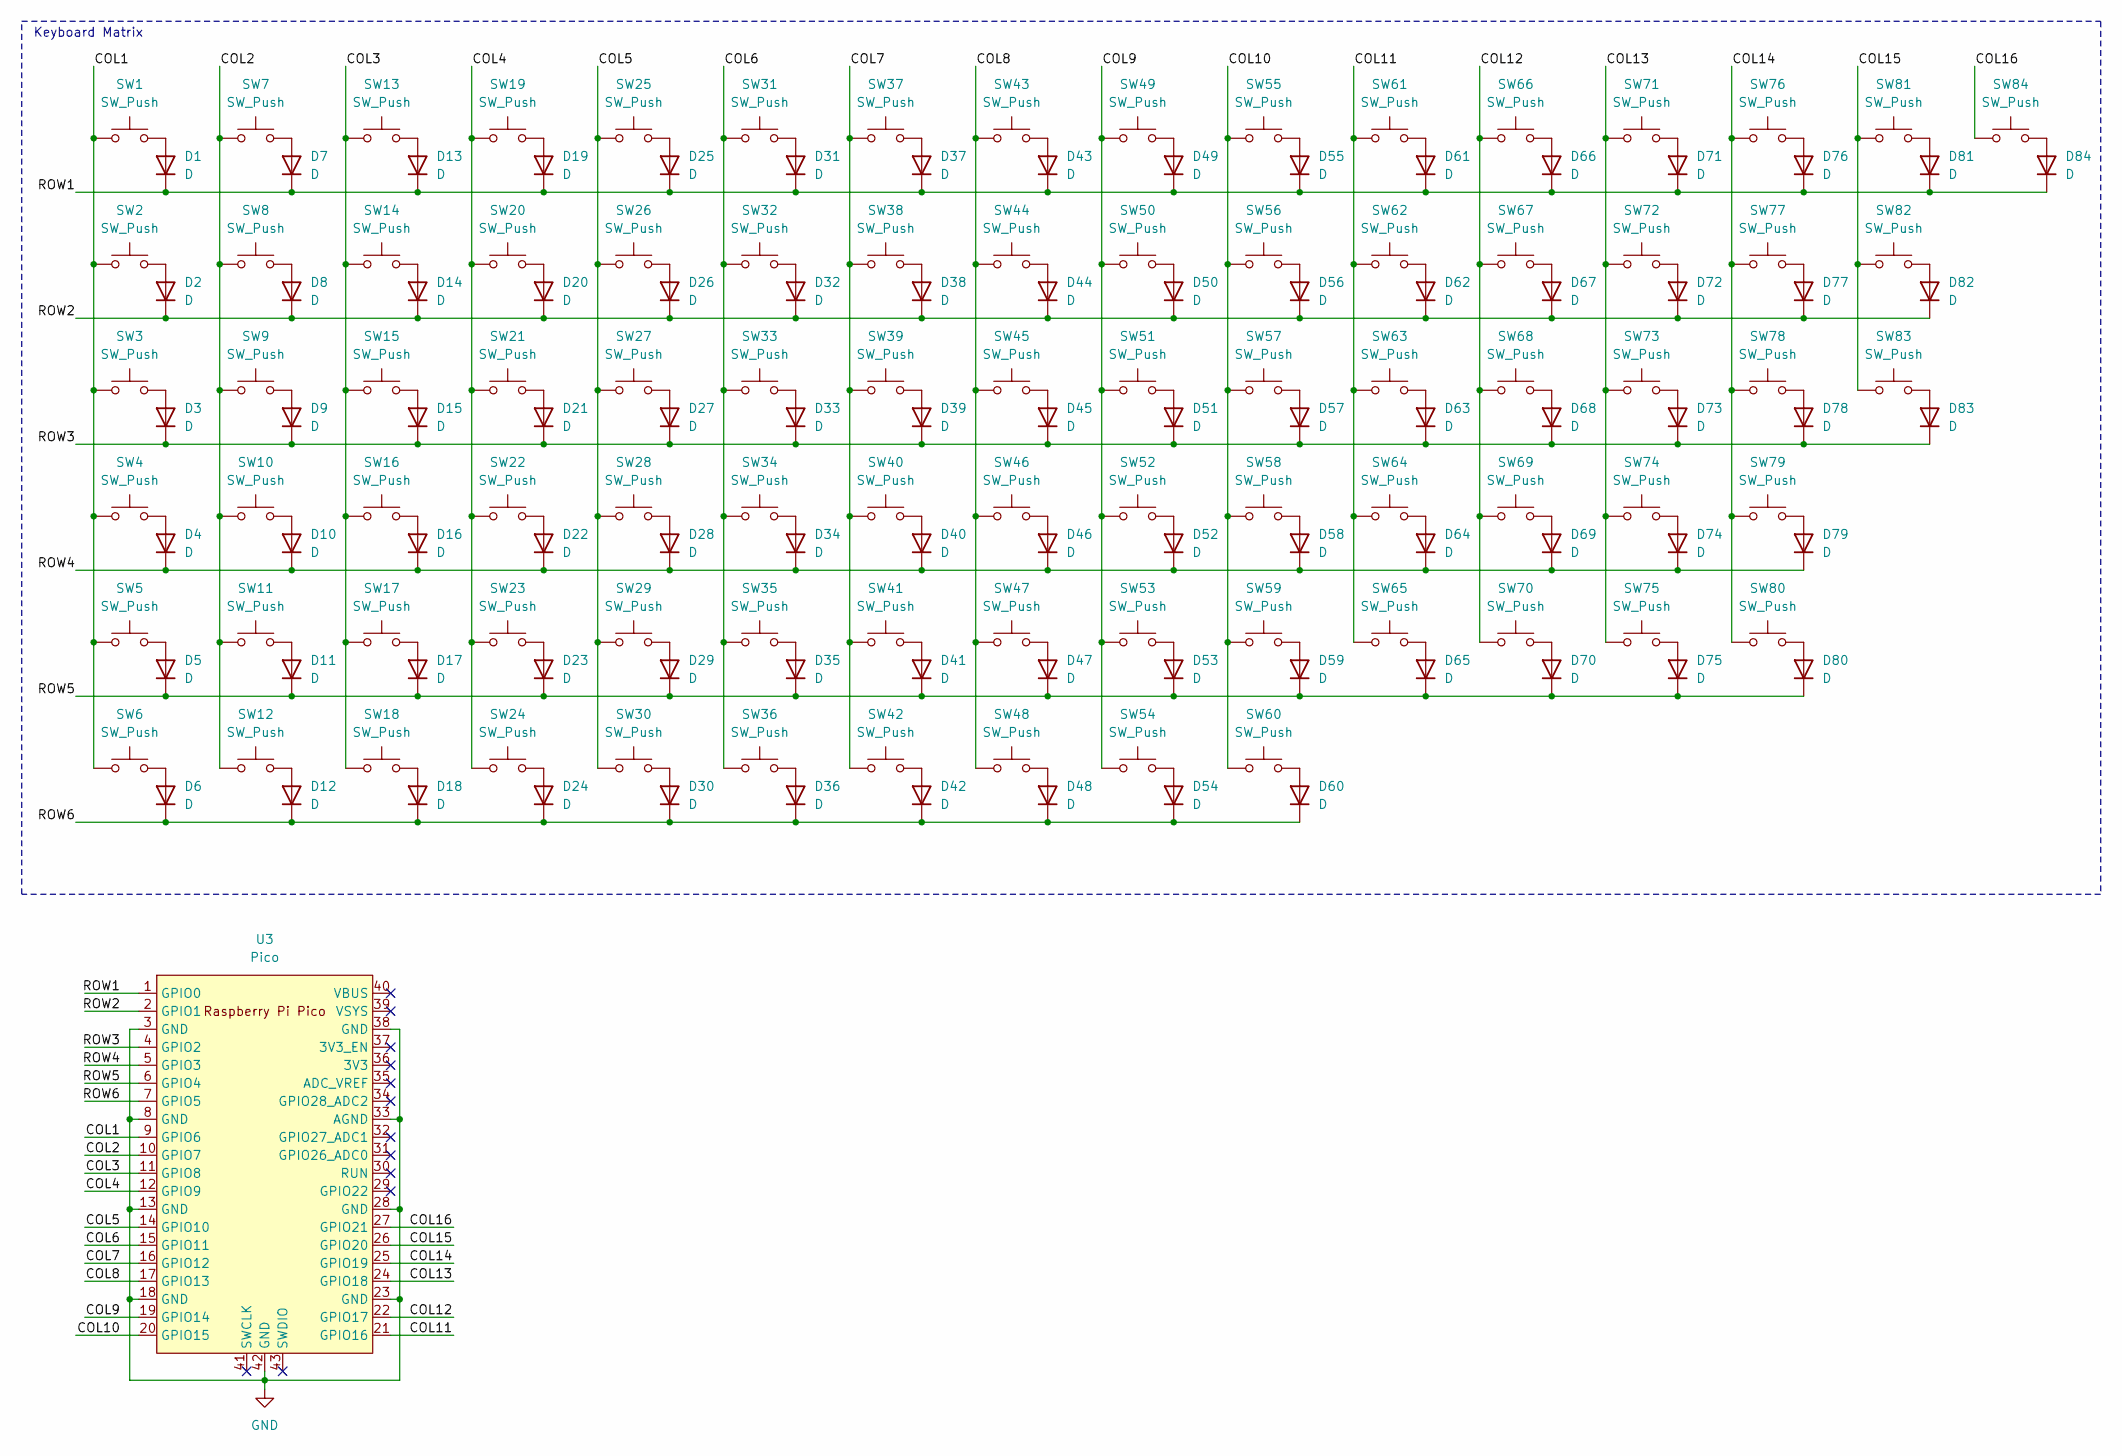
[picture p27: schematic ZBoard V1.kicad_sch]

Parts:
D1, D2, D3, D4, D5, D6, D7, D8, D9, D10, D11, D12, D13, D14, D15, D16, D17, D18, D19, D20, D21, D22, D23, D24, D25, D26, D27, D28, D29, D30, D31, D32, D33, D34, D35, D36, D37, D38, D39, D40, D41, D42, D43, D44, D45, D46, D47, D48, D49, D50, D51, D52, D53, D54, D55, D56, D57, D58, D59, D60, D61, D62, D63, D64, D65, D66, D67, D68, D69, D70, D71, D72, D73, D74, D75, D76, D77, D78, D79, D80, D81, D82, D83, D84: D; D_SOD-123
SW1, SW2, SW7, SW8, SW9, SW10, SW11, SW13, SW14, SW15, SW16, SW17, SW19, SW20, SW21, SW22, SW23, SW25, SW26, SW27, SW28, SW29, SW30, SW31, SW32, SW33, SW34, SW35, SW36, SW37, SW38, SW39, SW40, SW41, SW42, SW43, SW44, SW45, SW46, SW47, SW48, SW49, SW50, SW51, SW52, SW53, SW54, SW55, SW56, SW57, SW58, SW59, SW60, SW61, SW62, SW63, SW64, SW65, SW66, SW67, SW68, SW69, SW71, SW72, SW73, SW75, SW76, SW79, SW80, SW81, SW82, SW83, SW84: SW_Push; Gateron-KS33-Hotswap-1U
SW3, SW78: SW_Push; Gateron-KS33-Hotswap-1.5U
SW4, SW70: SW_Push; Gateron-KS33-Hotswap-1.75U
SW5, SW74: SW_Push; Gateron-KS33-Hotswap-2.25U
SW6, SW12, SW18: SW_Push; Gateron-KS33-Hotswap-1.25U
SW24: SW_Push; Gateron-KS33-Hotswap-6.25U
SW77: SW_Push; Gateron-KS33-Hotswap-2U
U3: Pico; RPi_Pico_SMD_TH

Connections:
/COL1: SW1.1, SW2.1, SW3.1, SW4.1, SW5.1, SW6.1, U3.9 (GPIO6)
/COL2: SW7.1, SW8.1, SW9.1, SW10.1, SW11.1, SW12.1, U3.10 (GPIO7)
/COL3: SW13.1, SW14.1, SW15.1, SW16.1, SW17.1, SW18.1, U3.11 (GPIO8)
/COL4: SW19.1, SW20.1, SW21.1, SW22.1, SW23.1, SW24.1, U3.12 (GPIO9)
/COL5: SW25.1, SW26.1, SW27.1, SW28.1, SW29.1, SW30.1, U3.14 (GPIO10)
/COL6: SW31.1, SW32.1, SW33.1, SW34.1, SW35.1, SW36.1, U3.15 (GPIO11)
/COL7: SW37.1, SW38.1, SW39.1, SW40.1, SW41.1, SW42.1, U3.16 (GPIO12)
/COL8: SW43.1, SW44.1, SW45.1, SW46.1, SW47.1, SW48.1, U3.17 (GPIO13)
/COL9: SW49.1, SW50.1, SW51.1, SW52.1, SW53.1, SW54.1, U3.19 (GPIO14)
/COL10: SW55.1, SW56.1, SW57.1, SW58.1, SW59.1, SW60.1, U3.20 (GPIO15)
/COL11: SW61.1, SW62.1, SW63.1, SW64.1, SW65.1, U3.21 (GPIO16)
/COL12: SW66.1, SW67.1, SW68.1, SW69.1, SW70.1, U3.22 (GPIO17)
/COL13: SW71.1, SW72.1, SW73.1, SW74.1, SW75.1, U3.24 (GPIO18)
/COL14: SW76.1, SW77.1, SW78.1, SW79.1, SW80.1, U3.25 (GPIO19)
/COL15: SW81.1, SW82.1, SW83.1, U3.26 (GPIO20)
/COL16: SW84.1, U3.27 (GPIO21)
/ROW1: D1.1 (K), D7.1 (K), D13.1 (K), D19.1 (K), D25.1 (K), D31.1 (K), D37.1 (K), D43.1 (K), D49.1 (K), D55.1 (K), D61.1 (K), D66.1 (K), D71.1 (K), D76.1 (K), D81.1 (K), D84.1 (K), U3.1 (GPIO0)
/ROW2: D2.1 (K), D8.1 (K), D14.1 (K), D20.1 (K), D26.1 (K), D32.1 (K), D38.1 (K), D44.1 (K), D50.1 (K), D56.1 (K), D62.1 (K), D67.1 (K), D72.1 (K), D77.1 (K), D82.1 (K), U3.2 (GPIO1)
/ROW3: D3.1 (K), D9.1 (K), D15.1 (K), D21.1 (K), D27.1 (K), D33.1 (K), D39.1 (K), D45.1 (K), D51.1 (K), D57.1 (K), D63.1 (K), D68.1 (K), D73.1 (K), D78.1 (K), D83.1 (K), U3.4 (GPIO2)
/ROW4: D4.1 (K), D10.1 (K), D16.1 (K), D22.1 (K), D28.1 (K), D34.1 (K), D40.1 (K), D46.1 (K), D52.1 (K), D58.1 (K), D64.1 (K), D69.1 (K), D74.1 (K), D79.1 (K), U3.5 (GPIO3)
/ROW5: D5.1 (K), D11.1 (K), D17.1 (K), D23.1 (K), D29.1 (K), D35.1 (K), D41.1 (K), D47.1 (K), D53.1 (K), D59.1 (K), D65.1 (K), D70.1 (K), D75.1 (K), D80.1 (K), U3.6 (GPIO4)
/ROW6: D6.1 (K), D12.1 (K), D18.1 (K), D24.1 (K), D30.1 (K), D36.1 (K), D42.1 (K), D48.1 (K), D54.1 (K), D60.1 (K), U3.7 (GPIO5)
GND: U3.3 (GND), U3.8 (GND), U3.13 (GND), U3.18 (GND), U3.23 (GND), U3.28 (GND), U3.33 (AGND), U3.38 (GND), U3.42 (GND)
unnamed: D1.2 (A), SW1.2
unnamed: D2.2 (A), SW2.2
unnamed: D3.2 (A), SW3.2
unnamed: D4.2 (A), SW4.2
unnamed: D5.2 (A), SW5.2
unnamed: D6.2 (A), SW6.2
unnamed: D7.2 (A), SW7.2
unnamed: D8.2 (A), SW8.2
unnamed: D9.2 (A), SW9.2
unnamed: D10.2 (A), SW10.2
unnamed: D11.2 (A), SW11.2
unnamed: D12.2 (A), SW12.2
unnamed: D13.2 (A), SW13.2
unnamed: D14.2 (A), SW14.2
unnamed: D15.2 (A), SW15.2
unnamed: D16.2 (A), SW16.2
unnamed: D17.2 (A), SW17.2
unnamed: D18.2 (A), SW18.2
unnamed: D19.2 (A), SW19.2
unnamed: D20.2 (A), SW20.2
unnamed: D21.2 (A), SW21.2
unnamed: D22.2 (A), SW22.2
unnamed: D23.2 (A), SW23.2
unnamed: D24.2 (A), SW24.2
unnamed: D25.2 (A), SW25.2
unnamed: D26.2 (A), SW26.2
unnamed: D27.2 (A), SW27.2
unnamed: D28.2 (A), SW28.2
unnamed: D29.2 (A), SW29.2
unnamed: D30.2 (A), SW30.2
unnamed: D31.2 (A), SW31.2
unnamed: D32.2 (A), SW32.2
unnamed: D33.2 (A), SW33.2
unnamed: D34.2 (A), SW34.2
unnamed: D35.2 (A), SW35.2
unnamed: D36.2 (A), SW36.2
unnamed: D37.2 (A), SW37.2
unnamed: D38.2 (A), SW38.2
unnamed: D39.2 (A), SW39.2
unnamed: D40.2 (A), SW40.2
unnamed: D41.2 (A), SW41.2
unnamed: D42.2 (A), SW42.2
unnamed: D43.2 (A), SW43.2
unnamed: D44.2 (A), SW44.2
unnamed: D45.2 (A), SW45.2
unnamed: D46.2 (A), SW46.2
unnamed: D47.2 (A), SW47.2
unnamed: D48.2 (A), SW48.2
unnamed: D49.2 (A), SW49.2
unnamed: D50.2 (A), SW50.2
unnamed: D51.2 (A), SW51.2
unnamed: D52.2 (A), SW52.2
unnamed: D53.2 (A), SW53.2
unnamed: D54.2 (A), SW54.2
unnamed: D55.2 (A), SW55.2
unnamed: D56.2 (A), SW56.2
unnamed: D57.2 (A), SW57.2
unnamed: D58.2 (A), SW58.2
unnamed: D59.2 (A), SW59.2
unnamed: D60.2 (A), SW60.2
unnamed: D61.2 (A), SW61.2
unnamed: D62.2 (A), SW62.2
unnamed: D63.2 (A), SW63.2
unnamed: D64.2 (A), SW64.2
unnamed: D65.2 (A), SW65.2
unnamed: D66.2 (A), SW66.2
unnamed: D67.2 (A), SW67.2
unnamed: D68.2 (A), SW68.2
unnamed: D69.2 (A), SW69.2
unnamed: D70.2 (A), SW70.2
unnamed: D71.2 (A), SW71.2
unnamed: D72.2 (A), SW72.2
unnamed: D73.2 (A), SW73.2
unnamed: D74.2 (A), SW74.2
unnamed: D75.2 (A), SW75.2
unnamed: D76.2 (A), SW76.2
unnamed: D77.2 (A), SW77.2
unnamed: D78.2 (A), SW78.2
unnamed: D79.2 (A), SW79.2
unnamed: D80.2 (A), SW80.2
unnamed: D81.2 (A), SW81.2
unnamed: D82.2 (A), SW82.2
unnamed: D83.2 (A), SW83.2
unnamed: D84.2 (A), SW84.2

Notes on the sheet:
Keyboard Matrix

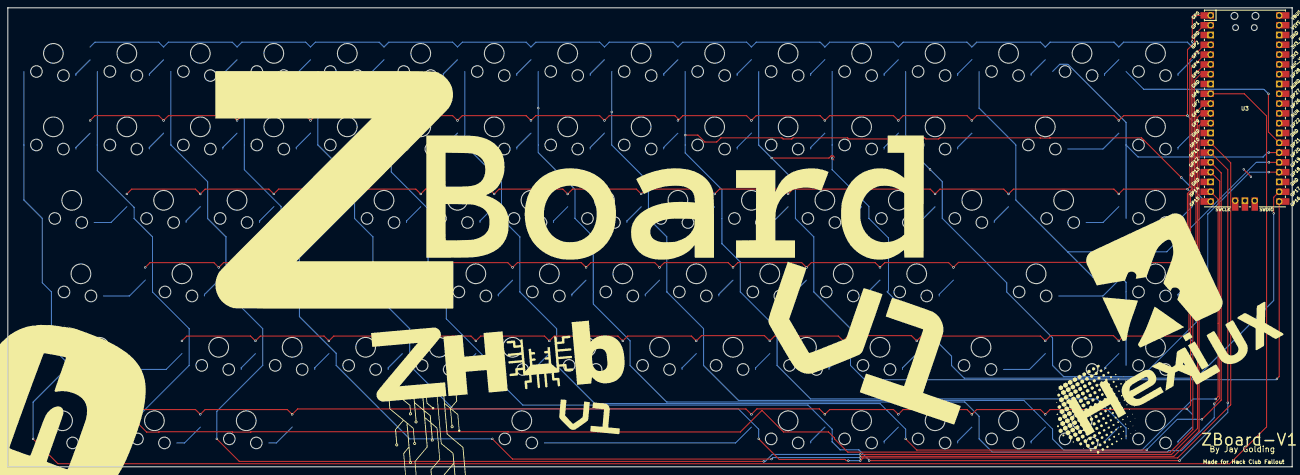
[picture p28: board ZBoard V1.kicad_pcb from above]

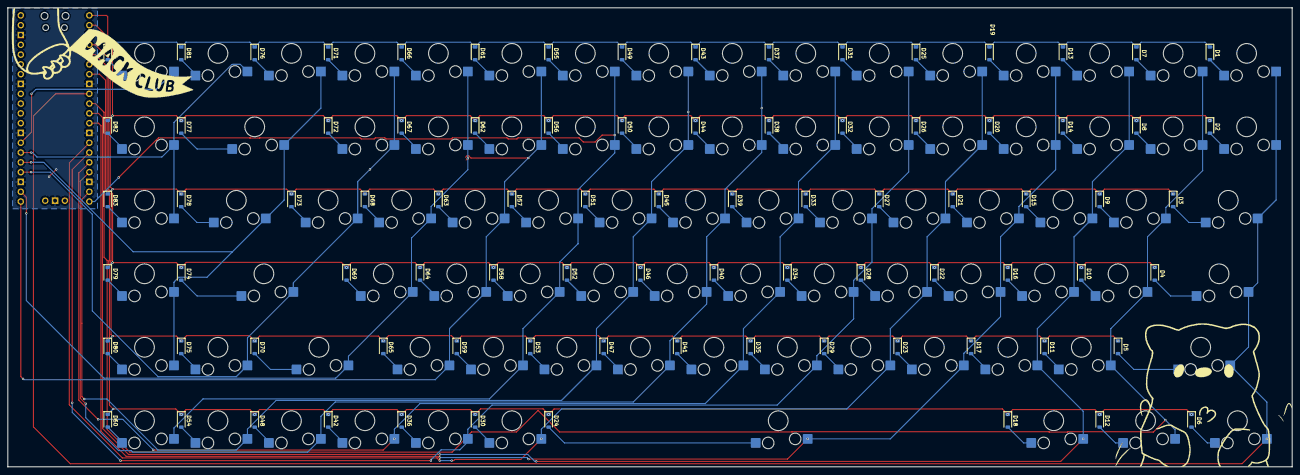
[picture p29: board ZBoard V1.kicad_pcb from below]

Board: 2 copper layers, 333.0 x 119.0 mm, 169 parts (168 on the bottom side), 107 nets.

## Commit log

2026-03-17 Add PCB files
    [ZBoard V1.kicad_pcb, ZBoard V1.kicad_sch, board.kicad_sch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]
2026-03-18 Change to 75% keyboard layout and move around PCB files
    [ZBoard V1.kicad_sch, board.kicad_sch, side.kicad_sch]
2026-03-19 Finish PCB routing
    [ZBoard V1.kicad_pcb, ZBoard V1.kicad_sch]
2026-03-21 Fix typo (thx brake)
2026-03-21 Reroute with switches on correct side
    [ZBoard V1.kicad_pcb]
2026-03-22 Add BOM
    [BOM.csv, ZBoard V1.csv]
2026-03-22 Update BOM with keycaps
    [BOM.csv, ZBoard V1.kicad_pcb, ZBoard-V1-PCB.step]
2026-03-22 Complete case, update BOM, start rendering images
    [BOM.csv, Keycap-Low-Profile-FDM.stl, ZBoard-V1-Bottom.step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]
2026-03-25 BOM + Case + Images & Video
    [Keycap-Low-Profile-FDM.stl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]
2026-03-25 Update BOM
    [BOM.csv]
2026-03-25 Add Journal.md and add progress
    [BOM.csv]
2026-03-28 Firmware. The largest pain in the world.
    [ZBoard V1.kicad_pcb]
2026-03-31 Added fancy silkscreen
    [ZBoard V1.kicad_pcb]
2026-04-02 Added Zine
    [ZBoard V1.kicad_pcb, ZBoard-V1-Top.step]
2026-04-03 Changed to 3D printed keycaps, changed parts sourcing, modified BOM
    [BOM.csv, KS-33 Low Profile 2.0.stp, Keycap-1.25u.step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]
2026-04-04 Fixed pinouts, fixed firmware
    [BOM.csv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]
2026-04-04 Update BOM and Journal
    [BOM.csv]
2026-04-04 Fix BOM for shipping
    [BOM.csv]
2026-04-04 Fixed BOM, added CAD source files, and added build guide.
    [BOM.csv, ZBoard-V1-Full.f3d, ZBoard-V1-Full.f3z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]
2026-04-04 Removing CAD source files
    [ZBoard-V1-Full.f3d]
2026-04-04 Readding CAD source files
    [ZBoard-V1-Full.f3d]
2026-04-04 Fix the issues pls work
    [BOM.csv, ZBoard V1.csv]
2026-04-25 Fix problems for fallout resubmission
    [ZBoard-V1-Full.f3d, ZBoard-V1-Full.stp]
2026-05-30 Beginning transition to wired using Orpheus Pico
    [ZBoard V1-B_Cu.gbr, ZBoard V1-B_Mask.gbr, ZBoard V1-B_Paste.gbr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]
2026-06-01 Finally got working firmware
    [ZBoard V1.kicad_pcb, ZBoard-V1-Bottom.step, ZBoard-V1-Bottom.stp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]
2026-06-01 Final commit pls
    [BOM.csv, ZBoard V1.csv]
2026-06-06 Make changes for resubmission (surely this time)
    [ZBoard-V1-Bottom.stp, ZBoard-V1-Full.f3d, ZBoard-V1-Full.stp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]
2026-06-07 Add more 'personality'
    [ZBoard-V1-Bottom.stp, ZBoard-V1-Full.f3d, ZBoard-V1-Full.stp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]
